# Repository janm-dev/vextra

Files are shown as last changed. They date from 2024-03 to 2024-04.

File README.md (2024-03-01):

# Vextra - Vehicle Extras

Vextra is an extensible system of vehicle (car, bicycle, motorbike, etc.) extras, including position tracking, smart accessories, and more.

## Repository Structure

- `api` - Vextra data access / API server
- `db` - Vextra database interface (support for Timescale DB and a debugging/testing stub)
- `firmware` - Vextra Device firmware (for ESP32-C6)
- `hardware` - Vextra Device schematic, PCB, and additional hardware design
- `ingest` - Vextra data ingest server (over UDP and HTTPS)
- `proto` - Vextra protocols
- `web` - Vextra website front-end

## Licenses

Vextra software (`api`, `db`, `firmware`, `ingest`, `proto`, and `web`) is licensed under the GNU AGPL v3 or later ([`AGPL-3.0-or-later`](https://spdx.org/licenses/AGPL-3.0-or-later.html)).
You can find the full license text in the `LICENSE-AGPL` file.

Vextra hardware (`hardware`) is **partially** licensed under the CERN Open Hardware Licence - Strongly Reciprocal Version 2 or later ([`CERN-OHL-S-2.0+`](https://ohwr.org/cern_ohl_s_v2.txt)).
See `hardware/README.md` for details, and the `LICENSE-OHL` file for the full text of the CERN OHL.

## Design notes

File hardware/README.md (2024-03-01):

# Vextra Device Hardware

Vextra hardware, including the device's schematic, PCB layout, and additional external hardware.

## Main Device Components

- MCU - ESP32-C6-WROOM-1(U)
- GNSS receiver - ST Teseo-VIC3DA or other pin-compatible modules (e.g. u-blox NEO series)
- Mobile transceiver - Waveshare SimCom SIM7600 module
- Battery - Li-Ion / Li-Po
- Battery Charger - TP4054
- Power supply - TPS54260 and HE9073
- Antennas - 2 x L1 or L1/L5 GNSS, 2 x 4G/3G/2G cellular, 1 x 2.4 GHz WiFi/BLE

## Device PCB

The PCB is split into three sections with slots between them: the power supply on the left, the MCU/GNSS section in the middle, and the cellular section on the right.

These sections are designed to be reusable for other purposes, e.g. the power supply section can act as a USB power supply or Li-Ion/Li-Po battery charger when removed from the rest of the board.
As such, not all components need to be installed for full operation for a specific purpose, e.g. the LEDs when low power consumption is needed or Q5 and Q6 when the USB port is not used as a power source for other USB devices.

## Additional Hardware

A case with mounting hardware for the Vextra Device is available as STEP files in `case` or [on Onshape](https://cad.onshape.com/documents/913efcab07442fbc03a0e56f/).

## Licenses

The schematic(s) and PCB(s) (KiCad files in this directory) are licensed under the CERN Open Hardware Licence - Strongly Reciprocal Version 2 or later ([`CERN-OHL-S-2.0+`](https://ohwr.org/cern_ohl_s_v2.txt)).

Additional external hardware (STEP files and associated documentation in subdirectories of this directory; e.g. the device's case and mounting hardware) are made available under the confusing and *iiuc* self-contradictory Onshape Free license (<https://www.onshape.com/en/legal/terms-of-use>, quoted below).
Commercial use might be - but probably isn't - allowed; use at your own risk and ask a lawyer.

> Onshape Free is a fully featured CAD and PDM platform perfect for **open-source** projects, makers, hobbyists and those learning to use modern CAD. This no-cost plan is meant for creating **non-commercial** product designs that are **open-source** publicly online.

*From <https://www.onshape.com/en/products/free> with added emphasis*

> \[...\] Customer grants a worldwide, royaltyfree and non-exclusive license to any End User or third party accessing the Public Document to use the intellectual property contained in Customer's Public Document without restriction, including without limitation the rights to use, copy, modify, merge, publish, distribute, sublicense, and/or sell copies of the Document, and to permit persons to whom the Document is made available to do the same.
> \[...\]
> Free versions of the Service are intended to support (a) creating and editing intellectual property for non-commercial purposes \[...\]

*From <https://www.onshape.com/en/legal/terms-of-use>*

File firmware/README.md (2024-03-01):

# Vextra Device Firmware

The firmware for the ESP32-C6-based Vextra Device.

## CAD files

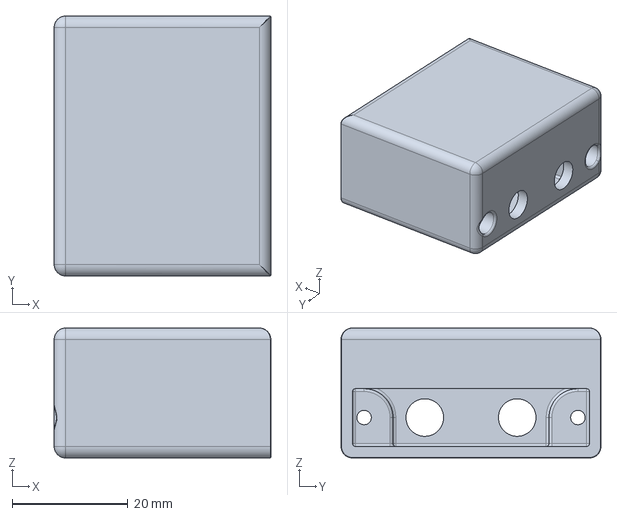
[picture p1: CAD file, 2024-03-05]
hardware/case/left.step
37.5 x 45.0 x 22.5 mm

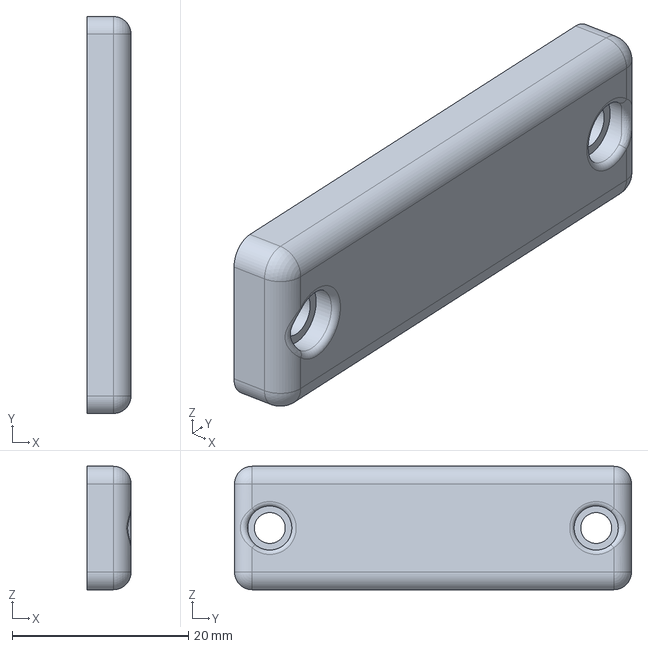
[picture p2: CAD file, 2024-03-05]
hardware/case/endcap.step
5.00 x 45.0 x 14.0 mm

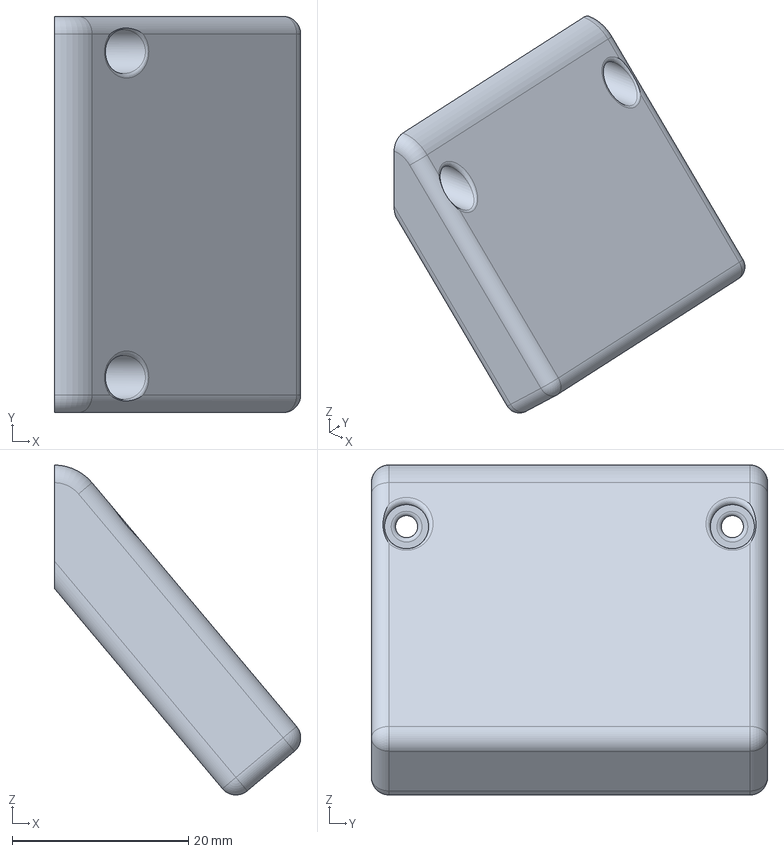
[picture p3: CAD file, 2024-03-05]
hardware/case/right.step
28.0 x 45.0 x 37.5 mm

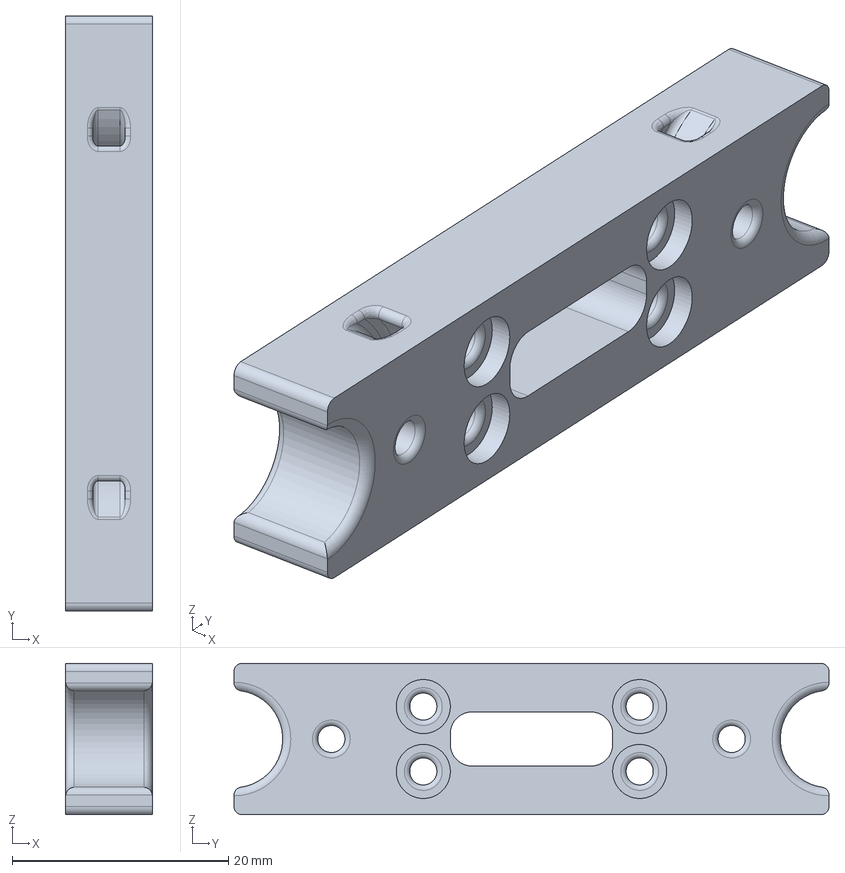
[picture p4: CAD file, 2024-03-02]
hardware/case/mount.step
8.00 x 55.0 x 14.0 mm

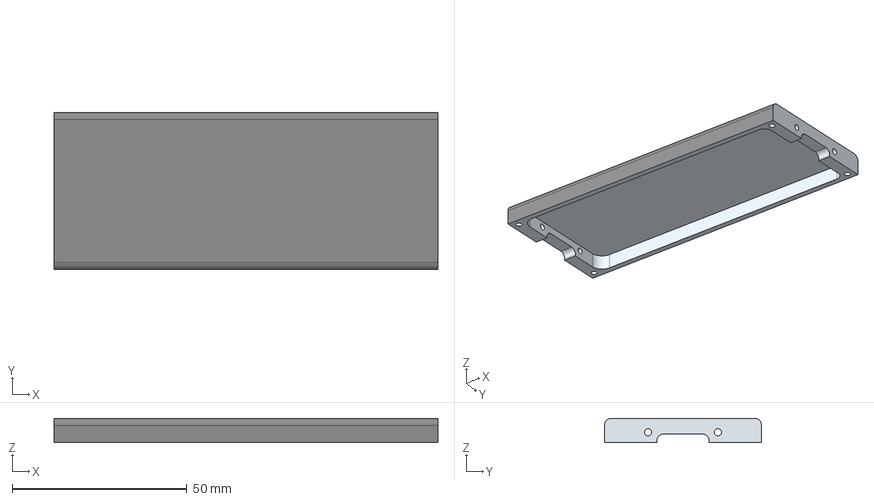
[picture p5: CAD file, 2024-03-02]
hardware/case/top.step
110.0 x 45.0 x 7.00 mm

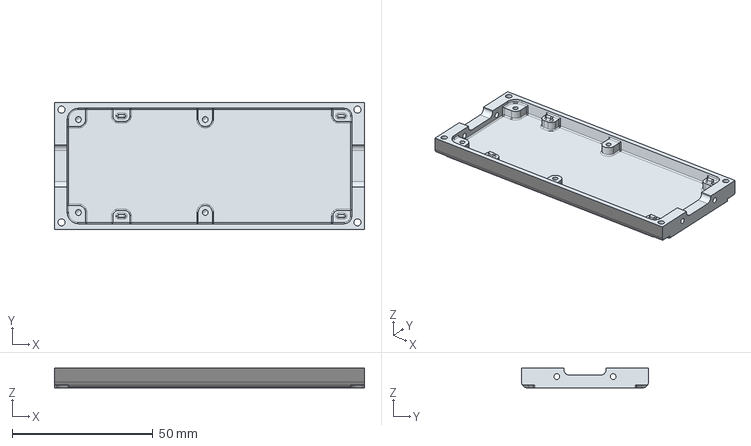
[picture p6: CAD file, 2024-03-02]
hardware/case/bottom.step
110.0 x 45.0 x 7.00 mm

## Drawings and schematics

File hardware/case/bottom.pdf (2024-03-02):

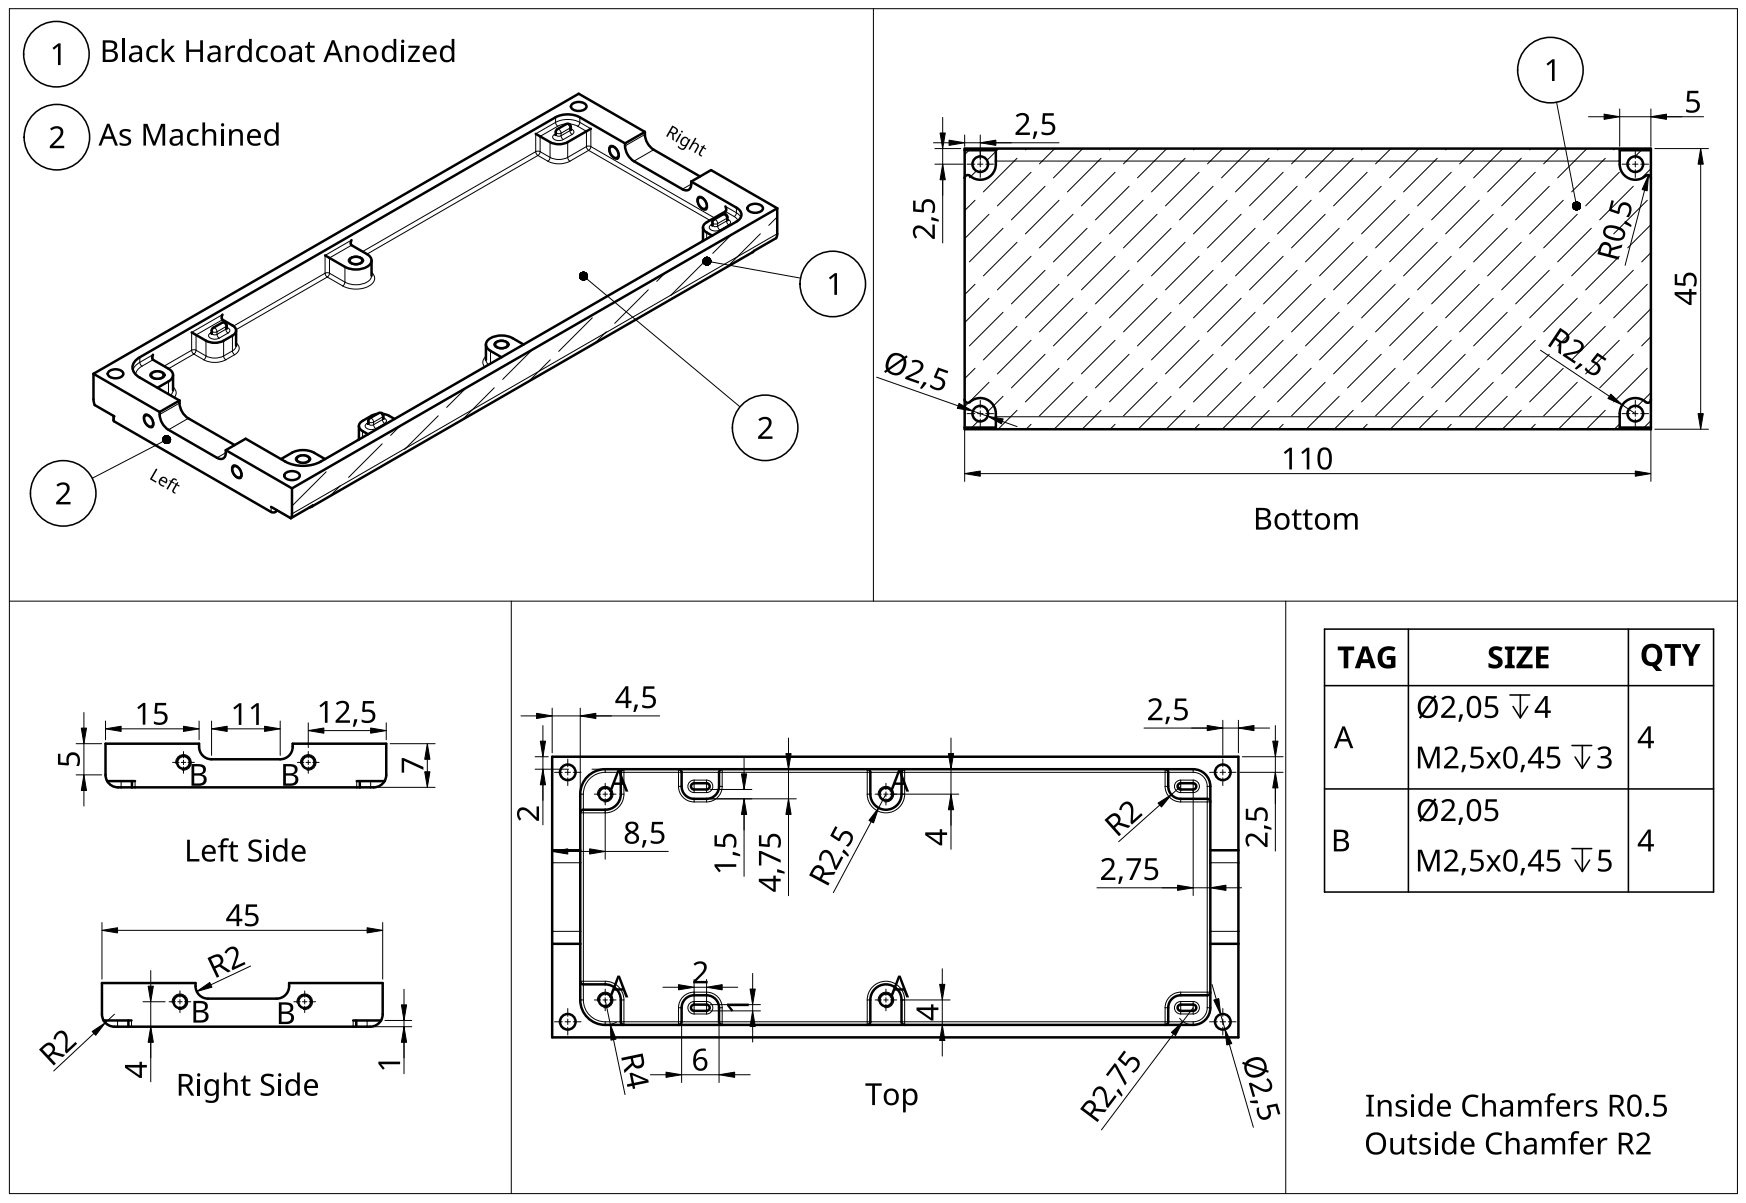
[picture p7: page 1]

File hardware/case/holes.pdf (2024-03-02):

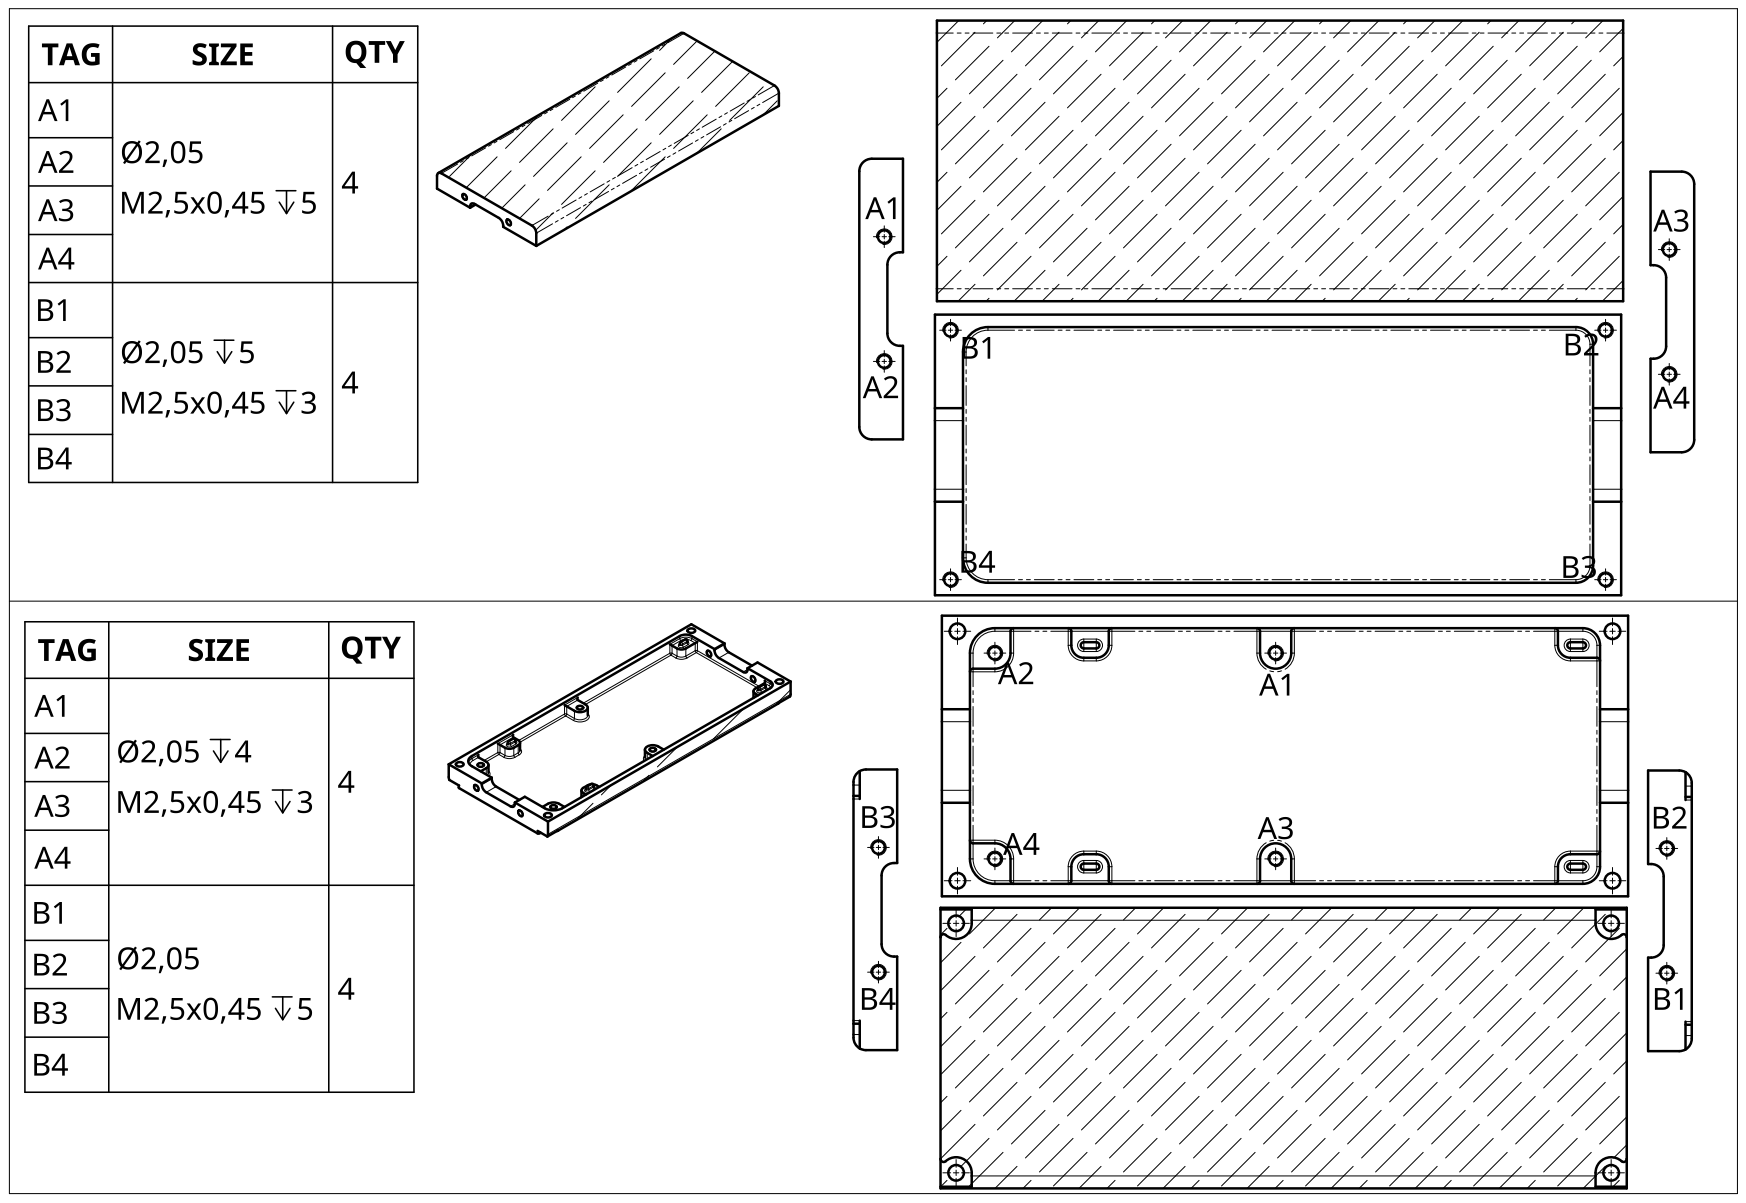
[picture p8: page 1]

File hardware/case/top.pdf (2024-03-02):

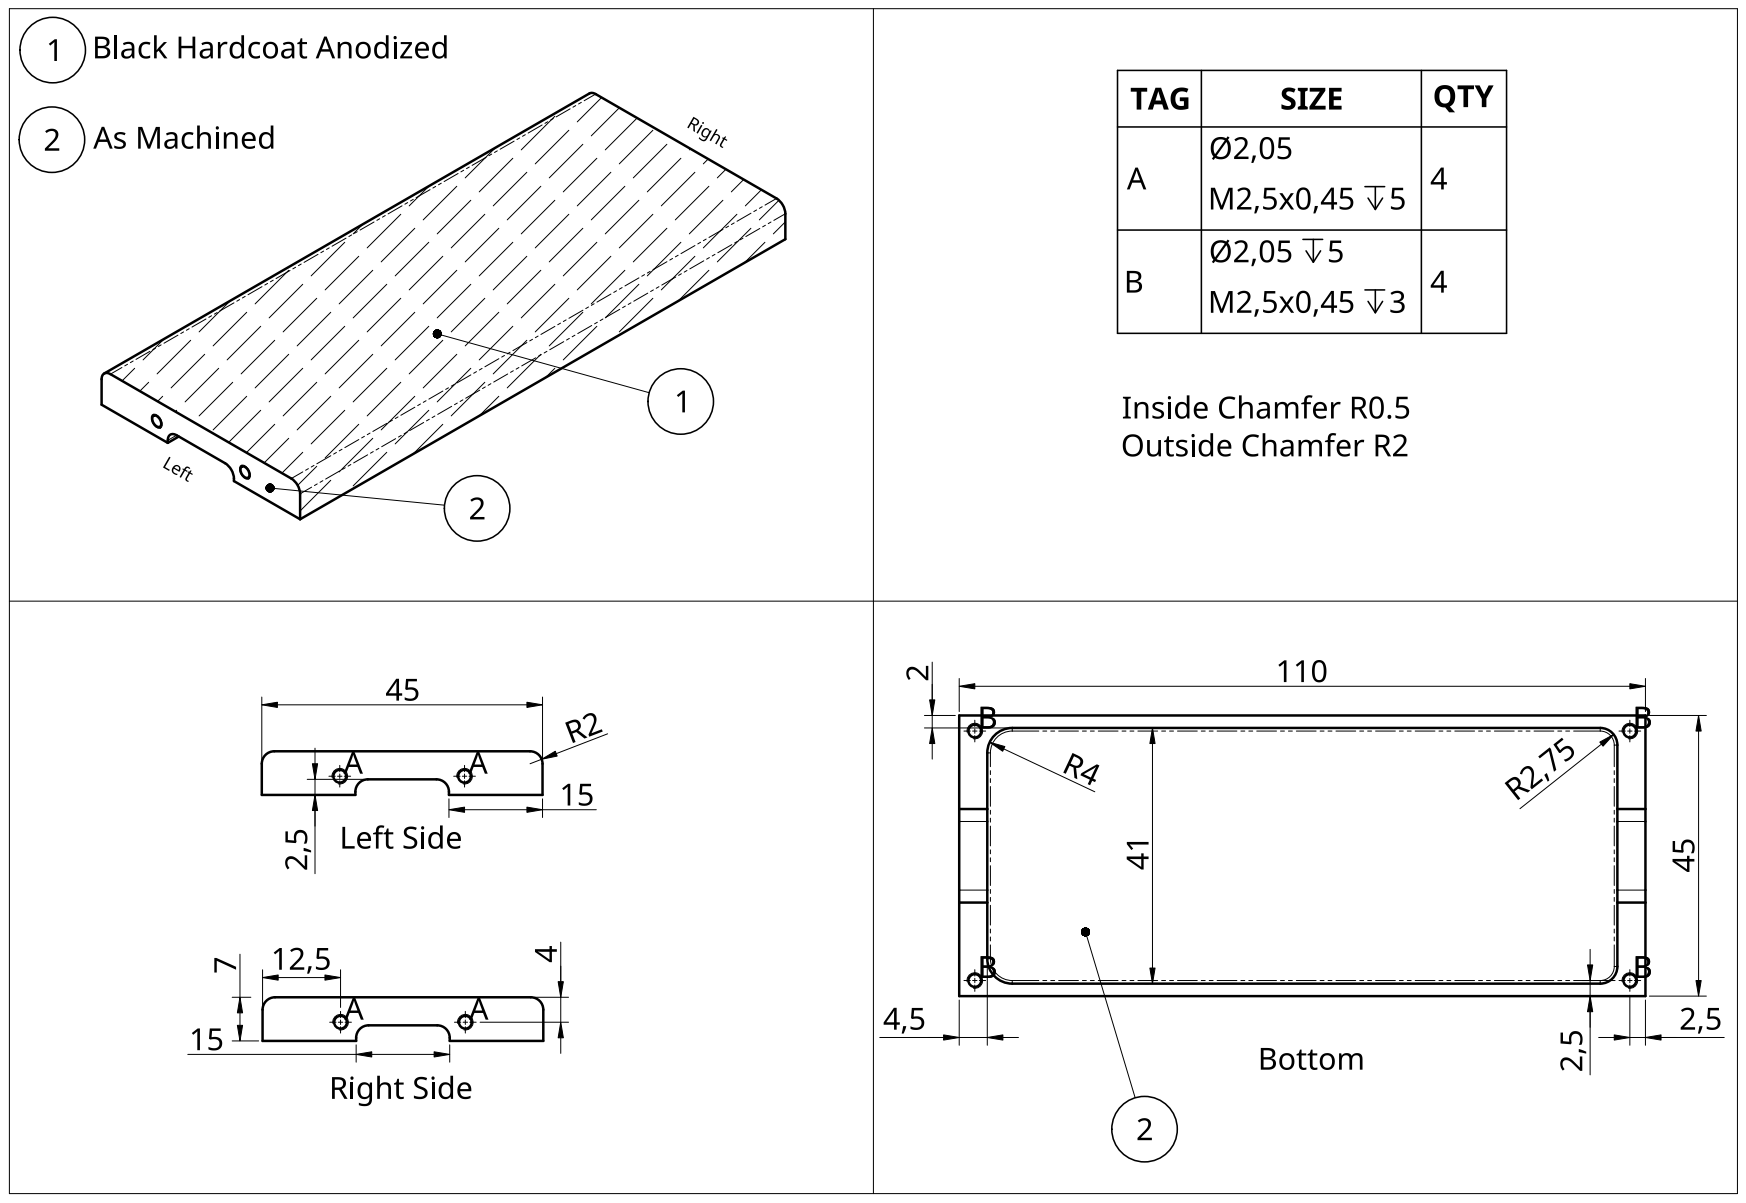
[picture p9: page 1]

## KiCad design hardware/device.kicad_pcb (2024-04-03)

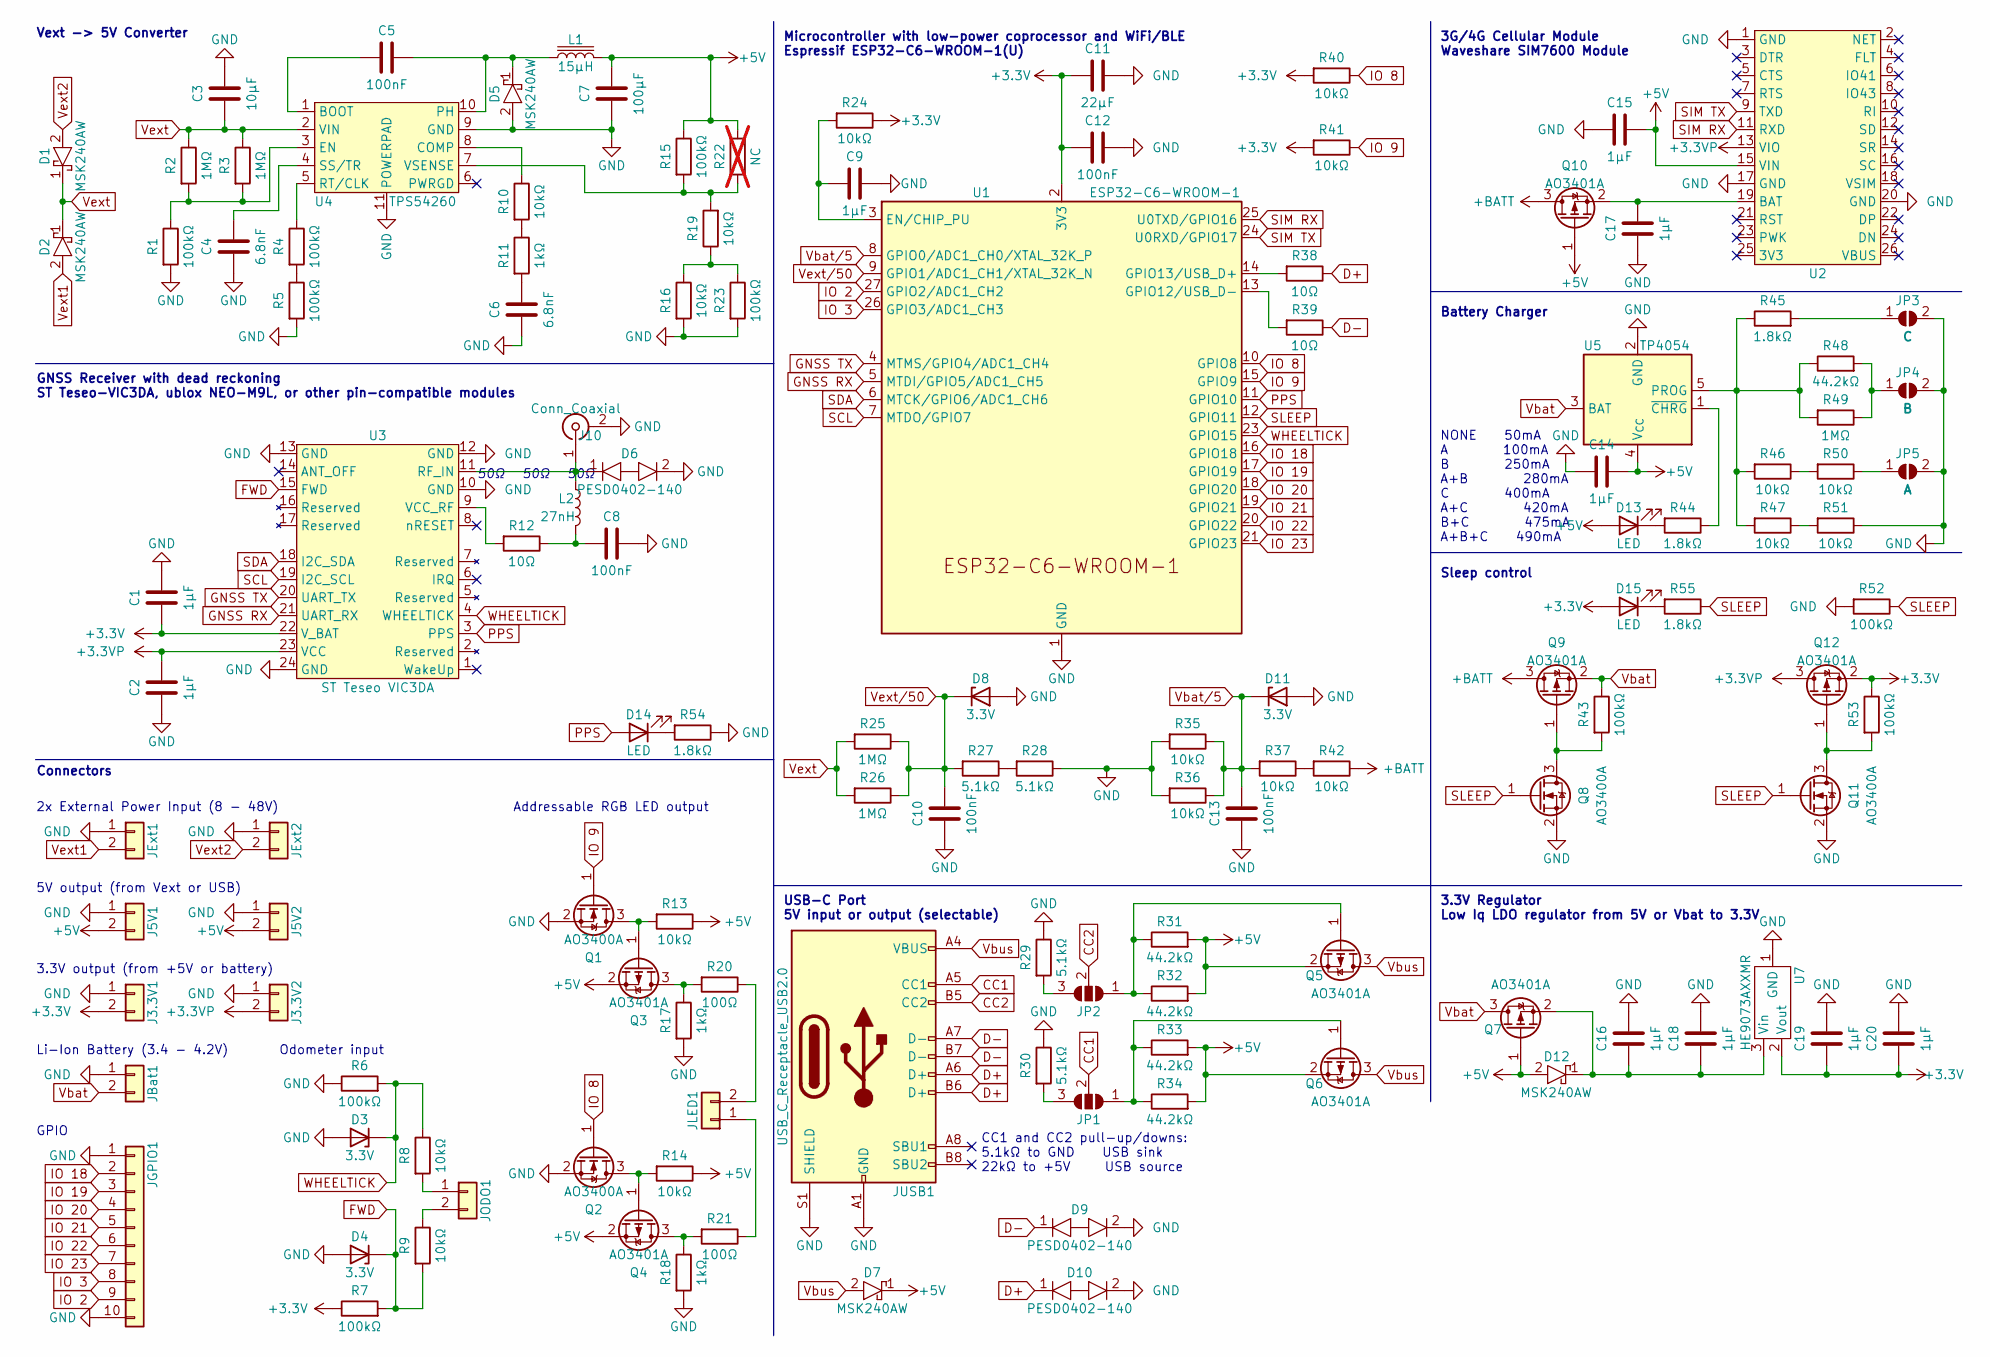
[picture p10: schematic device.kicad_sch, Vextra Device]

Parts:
C1, C2, C9, C14, C15, C16, C17, C18, C19, C20: 1µF; C_0603_1608Metric
C3: 10µF; C_0805_2012Metric
C4, C6: 6.8nF; C_0603_1608Metric
C5, C8, C10, C12, C13: 100nF; C_0603_1608Metric
C7: 100µF; C_1206_3216Metric
C11: 22µF; C_0603_1608Metric
D1, D2, D5, D7, D12: MSK240AW
D3, D4, D8, D11: 3.3V; SMAF
D6, D9, D10: PESD0402-140; D_0402_1005Metric
D13, D14, D15: LED; LED_0603_1608Metric
J3.3V1, J5V1: Conn_01x02; PinHeader_1x02_P2.54mm_Vertical
J3.3V2, J5V2: Conn_01x02; PH-2AWD
J10: Conn_Coaxial; U.FL_Hirose_U.FL-R-SMT-1_Vertical
JBat1: Conn_01x02; PH-2AWD
JExt1, JExt2: Conn_01x02; PH-2AWD
JGPIO1: Conn_01x10; PinHeader_1x10_P2.54mm_Vertical
JLED1: Conn_01x02; PH-2AWD
JODO1: Conn_01x02; PH-2AWD
JP1, JP2: SolderJumper_3_Open; SolderJumper-3_P1.3mm_Open_RoundedPad1.0x1.5mm
JP3: C; SolderJumper-2_P1.3mm_Open_RoundedPad1.0x1.5mm
JP4: B; SolderJumper-2_P1.3mm_Open_RoundedPad1.0x1.5mm
JP5: A; SolderJumper-2_P1.3mm_Open_RoundedPad1.0x1.5mm
JUSB1: USB_C_Receptacle_USB2.0; USB_C_Receptacle_HRO_TYPE-C-31-M-12
L1: 15µH; Inductor SMD 11.6x10.1
L2: 27nH; L_0603_1608Metric
Q1, Q2, Q8, Q11: AO3400A; SOT-23
Q3, Q4, Q5, Q6, Q7, Q9, Q10, Q12: AO3401A; SOT-23
R1, R4, R5, R6, R7, R15, R23, R43, R52, R53: 100kΩ; R_0603_1608Metric
R2, R3, R25, R26, R49: 1MΩ; R_0603_1608Metric
R8, R9, R10, R13, R14, R16, R19, R24, R35, R36, R37, R40, R41, R42, R46, R47, R50, R51: 10kΩ; R_0603_1608Metric
R11, R17, R18: 1kΩ; R_0603_1608Metric
R12, R38, R39: 10Ω; R_0603_1608Metric
R20, R21: 100Ω; R_0603_1608Metric
R22: NC; R_0603_1608Metric; not fitted
R27, R28, R29, R30: 5.1kΩ; R_0603_1608Metric
R31, R32, R33, R34, R48: 44.2kΩ; R_0603_1608Metric
R44, R45, R54, R55: 1.8kΩ; R_0603_1608Metric
U1: ESP32-C6-WROOM-1; ESP32-C6-WROOM-1U
U2: Waveshare SIM7600G-H Module THT
U3: ST Teseo VIC3DA
U4: TPS54260; TPS54260DGQR
U5: TP4054; TSOT-23-5
U7: HE9073AXXMR; SOT-23

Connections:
+3.3V: C1.1, C11.1, C12.1, C19.1, C20.1, D15.2 (A), J3.3V1.2, Q12.2 (S), R7.1, R24.1, R40.2, R41.2, R53.1, U1.2 (3V3), U3.22 (V_BAT), U7.2 (Vout)
+3.3VP: C2.2, J3.3V2.2, Q12.3 (D), U2.13 (VIO), U3.23 (VCC)
+5V: C7.2, C14.2, C15.2, D7.1, D12.2, D13.2 (A), J5V1.2, J5V2.2, L1.2, Q3.2 (S), Q4.2 (S), Q5.2 (S), Q6.2 (S), Q7.1 (G), Q10.1 (G), R13.1, R14.1, R15.1, R22.1, R31.2, R32.2, R33.2, R34.2, U2.15 (VIN), U5.4 (V_{CC})
+BATT: Q9.3 (D), Q10.3 (D), R42.1
CC1: JP1.2 (C), JUSB1.A5 (CC1)
CC2: JP2.2 (C), JUSB1.B5 (CC2)
D+: D10.1, JUSB1.A6 (D+), JUSB1.B6 (D+), R38.1
D-: D9.1, JUSB1.A7 (D-), JUSB1.B7 (D-), R39.1
FWD: D4.1 (K), R7.2, R9.2, U3.15 (FWD)
GND: C1.2, C2.1, C3.2, C4.1, C6.1, C7.1, C8.2, C9.2, C10.1, C11.2, C12.2, C13.1, C14.1, C15.1, C16.1, C17.1, C18.1, C19.2, C20.2, D3.2 (A), D4.2 (A), D5.2, D6.2, D8.2 (A), D9.2, D10.2, D11.2 (A), J3.3V1.1, J3.3V2.1, J5V1.1, J5V2.1, J10.2 (Ext), JBat1.1, JExt1.1, JExt2.1, JGPIO1.1, JGPIO1.10, JP3.2 (B), JP4.2 (B), JP5.2 (B), JUSB1.A1 (GND), JUSB1.A12 (GND), JUSB1.B1 (GND), JUSB1.B12 (GND), JUSB1.S1 (SHIELD), Q1.2 (S), Q2.2 (S), Q8.2 (S), Q11.2 (S), R1.2, R5.2, R6.1, R16.2, R17.2, R18.2, R23.2, R28.1, R29.1, R30.1, R35.2, R36.2, R51.1, R52.2, R54.1, U1.1 (GND), U1.28 (GND), U1.29 (GND), U2.1 (GND), U2.17 (GND), U2.20 (GND), U3.10 (GND), U3.12 (GND), U3.13 (GND), U3.24 (GND), U4.9 (GND), U4.11 (POWERPAD), U5.2 (GND), U7.1 (GND)
GNSS RX: U1.5 (MTDI/GPIO5/ADC1_CH5), U3.21 (UART_RX)
GNSS TX: U1.4 (MTMS/GPIO4/ADC1_CH4), U3.20 (UART_TX)
IO 2: JGPIO1.9, U1.27 (GPIO2/ADC1_CH2)
IO 3: JGPIO1.8, U1.26 (GPIO3/ADC1_CH3)
IO 8: Q2.1 (G), R40.1, U1.10 (GPIO8)
IO 9: Q1.1 (G), R41.1, U1.15 (GPIO9)
IO 18: JGPIO1.2, U1.16 (GPIO18)
IO 19: JGPIO1.3, U1.17 (GPIO19)
IO 20: JGPIO1.4, U1.18 (GPIO20)
IO 21: JGPIO1.5, U1.19 (GPIO21)
IO 22: JGPIO1.6, U1.20 (GPIO22)
IO 23: JGPIO1.7, U1.21 (GPIO23)
unnamed: C6.2, R11.2
unnamed: C8.1, L2.2, R12.1
unnamed: D13.1 (K), R44.2
unnamed: D14.1 (K), R54.2
unnamed: D15.1 (K), R55.2
unnamed: D6.1, J10.1 (In), L2.1, U3.11 (RF_IN)
unnamed: JLED1.1, R21.1
unnamed: JLED1.2, R20.1
unnamed: JODO1.1, R8.2
unnamed: JODO1.2, R9.1
unnamed: JP1.1 (A), Q6.1 (G), R33.1, R34.1
unnamed: JP1.3 (B), R30.2
unnamed: JP2.1 (A), Q5.1 (G), R31.1, R32.1
unnamed: JP2.3 (B), R29.2
unnamed: JP3.1 (A), R45.2
unnamed: JP4.1 (A), R48.2, R49.1
unnamed: JP5.1 (A), R50.1
unnamed: Q1.3 (D), Q3.1 (G), R13.2
unnamed: Q2.3 (D), Q4.1 (G), R14.2
unnamed: Q3.3 (D), R17.1, R20.2
unnamed: Q4.3 (D), R18.1, R21.2
unnamed: C16.2, C18.2, D12.1, Q7.2 (S), U7.3 (Vin)
unnamed: Q8.3 (D), Q9.1 (G), R43.2
unnamed: C17.2, Q10.2 (S), U2.19 (BAT)
unnamed: Q11.3 (D), Q12.1 (G), R53.2
unnamed: R4.2, R5.1
unnamed: R10.2, R11.1
unnamed: R16.1, R19.1, R23.1
unnamed: R27.1, R28.2
unnamed: R37.1, R42.2
unnamed: R46.1, R50.2
unnamed: R47.1, R51.2
unnamed: C9.1, R24.2, U1.3 (EN/CHIP_PU)
unnamed: R39.2, U1.13 (GPIO12/USB_D-)
unnamed: R38.2, U1.14 (GPIO13/USB_D+)
unnamed: R12.2, U3.9 (VCC_RF)
unnamed: C5.1, U4.1 (BOOT)
unnamed: R10.1, U4.8 (COMP)
unnamed: R1.1, R2.2, R3.2, U4.3 (EN)
unnamed: C5.2, D5.1, L1.1, U4.10 (PH)
unnamed: R4.1, U4.5 (RT/CLK)
unnamed: C4.2, U4.4 (SS/TR)
unnamed: R15.2, R19.2, R22.2, U4.7 (VSENSE)
unnamed: R45.1, R46.2, R47.2, R48.1, R49.2, U5.5 (PROG)
unnamed: R44.1, U5.1 (~CHRG)
PPS: D14.2 (A), U1.11 (GPIO10), U3.3 (PPS)
SCL: U1.7 (MTDO/GPIO7), U3.19 (I2C_SCL)
SDA: U1.6 (MTCK/GPIO6/ADC1_CH6), U3.18 (I2C_SDA)
SIM RX: U1.25 (U0TXD/GPIO16), U2.11 (RXD)
SIM TX: U1.24 (U0RXD/GPIO17), U2.9 (TXD)
SLEEP: Q8.1 (G), Q11.1 (G), R52.1, R55.1, U1.12 (GPIO11)
Vbat: JBat1.2, Q7.3 (D), Q9.2 (S), R43.1, U5.3 (BAT)
Vbat/5: C13.2, D11.1 (K), R35.1, R36.1, R37.2, U1.8 (GPIO0/ADC1_CH0/XTAL_32K_P)
Vbus: D7.2, JUSB1.A4 (VBUS), JUSB1.A9 (VBUS), JUSB1.B4 (VBUS), JUSB1.B9 (VBUS), Q5.3 (D), Q6.3 (D)
Vext: C3.1, D1.1, D2.1, R2.1, R3.1, R25.2, R26.2, U4.2 (VIN)
Vext1: D2.2, JExt1.2
Vext2: D1.2, JExt2.2
Vext/50: C10.2, D8.1 (K), R25.1, R26.1, R27.2, U1.9 (GPIO1/ADC1_CH1/XTAL_32K_N)
WHEELTICK: D3.1 (K), R6.2, R8.1, U1.23 (GPIO15), U3.4 (WHEELTICK)

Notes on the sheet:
2x External Power Input (8 - 48V)
Battery Charger
50Ω
NONE 50mA A 100mA B 250mA A+B 280mA C 400mA A+C 420mA B+C 475mA A+B+C 490mA
3.3V Regulator Low Iq LDO regulator from 5V or Vbat to 3.3V
3.3V output (from +5V or battery)
5V output (from Vext or USB)
Sleep control
GNSS Receiver with dead reckoning ST Teseo-VIC3DA, ublox NEO-M9L, or other pin-compatible modules
Addressable RGB LED output
GPIO
Vext -> 5V Converter
Connectors
CC1 and CC2 pull-up/downs: 5.1kΩ to GND USB sink 22kΩ to +5V USB source
Microcontroller with low-power coprocessor and WiFi/BLE Espressif ESP32-C6-WROOM-1(U)
USB-C Port 5V input or output (selectable)
Li-Ion Battery (3.4 - 4.2V)
Odometer input
3G/4G Cellular Module Waveshare SIM7600 Module

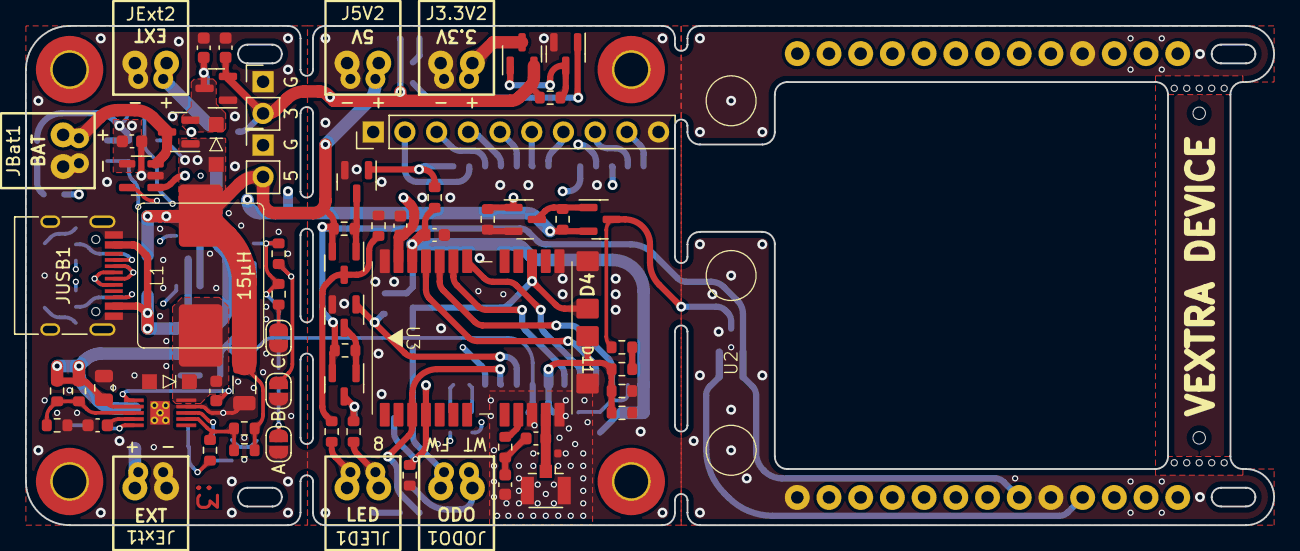
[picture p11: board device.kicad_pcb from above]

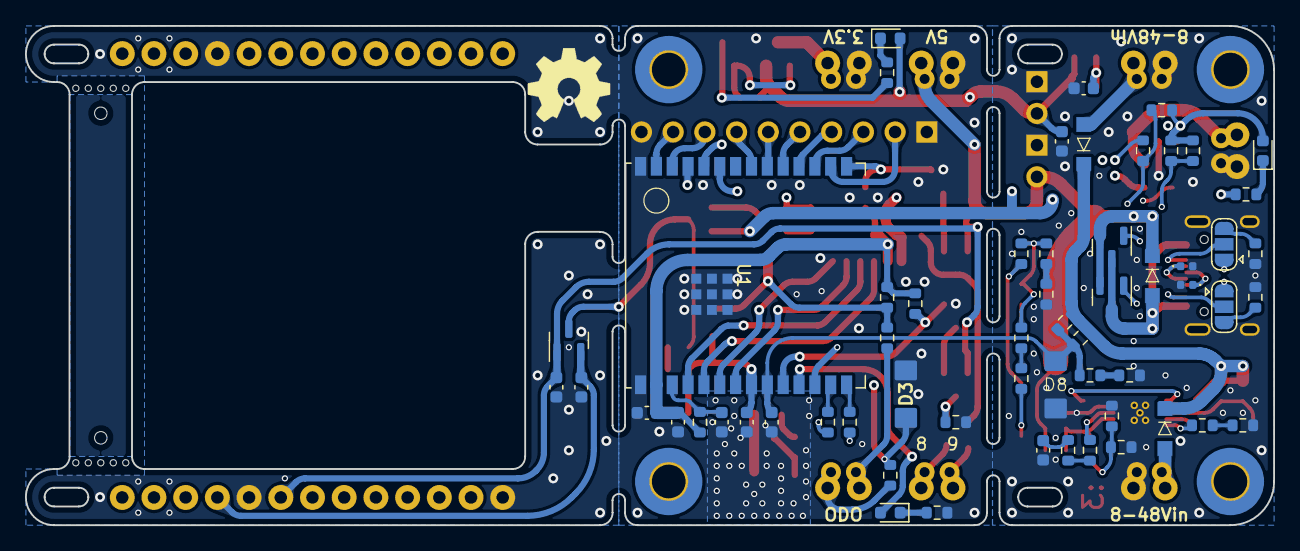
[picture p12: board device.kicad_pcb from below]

Board: 4 copper layers, 100.0 x 40.0 mm, 127 parts (58 on the bottom side), 81 nets.

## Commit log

2024-03-02 feat(hardware): add device schematics and pcb
    [device.kicad_pcb, device.kicad_sch]
2024-03-02 feat(hardware): add device case
    [bottom.step, top.step]
2024-03-02 feat(hardware): add case mount
    [mount.step]
2024-03-05 feat(hardware): add case endcaps
    [endcap.step, left.step, right.step]
2024-04-03 fix(hardware): fix 5V divider resistors
    oops, i forgot some parentheses when calculating them initially
    [device.kicad_pcb, device.kicad_sch]
